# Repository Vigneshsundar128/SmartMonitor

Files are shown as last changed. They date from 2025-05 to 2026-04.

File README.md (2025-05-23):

# Smart Monitor

**Smart Monitor** is an indigenous IoT product designed to monitor energy consumption along with additional features such as weather monitoring, date, and time display. This device leverages open-source libraries and custom firmware with Over-The-Air (OTA) updates to eliminate wired communication, enabling seamless firmware upgrades for continuous feature development and integration within a complete smart ecosystem.

## Features

- Real-time monitoring of energy consumption (voltage, current, power)
- Local temperature and humidity measurement
- Weather updates using OpenWeatherMap API
- Date and time synchronization via NTP server
- OTA firmware updates for hassle-free enhancements
- Web interface hosted on the device for power monitoring
- Non-blocking, efficient firmware using timers, counters, and interrupts

## Hardware Components

- **ESP8266EX** — 32-bit Tensilica® processor-based microcontroller  
- **LCD 20x4** — for local data display (I2C communication)  
- **DHT11** — temperature and humidity sensor  
- **PZEM-004T** — voltage and current sensor (UART communication)  

## Software and Libraries Used

- **Firmware:** Developed using advanced embedded concepts (non-blocking methods, timers, counters, interrupts)  
- **OTA Updates:** [Elegant OTA](https://docs.elegantota.pro/) — open-source library for wireless firmware updates  
- **Weather Data:** OpenWeatherMap API  
- **Time Sync:** NTP server  
- **Web Interface:** Power monitoring webpage adapted from [HowToElectronics](https://howtoelectronics.com)  

## Installation and Setup

1. Install dependencies and libraries (e.g., Elegant OTA, DHT11 library, etc.) through your preferred IDE (e.g., Arduino IDE).

2. Configure WiFi credentials and OpenWeatherMap API key in the firmware source code.

3. Flash the firmware to ESP8266EX using OTA or wired connection for first upload.

4. Access the web interface via the ESP8266 IP address to monitor data.

## Usage

- View energy consumption, temperature, humidity, weather data, date, and time on the LCD display.

- Access the hosted web page on ESP8266 for detailed power monitoring.

- OTA updates allow you to upload new firmware versions without physical connection.

## Project Status

This project is currently active and under continuous development for additional features and optimizations. This have both IoT and IoT firmware. 

## Contribution

Contributions are welcome! Feel free to open issues or submit pull requests with improvements.

## License

This project is licensed under the MIT License. See the LICENSE file for details.

## Author

Vignesh Sundar

LinkedIn: https://www.linkedin.com/in/vignesh-sundar-m/

## References

Elegant OTA Library

OpenWeatherMap API

HowToElectronics for Webpage

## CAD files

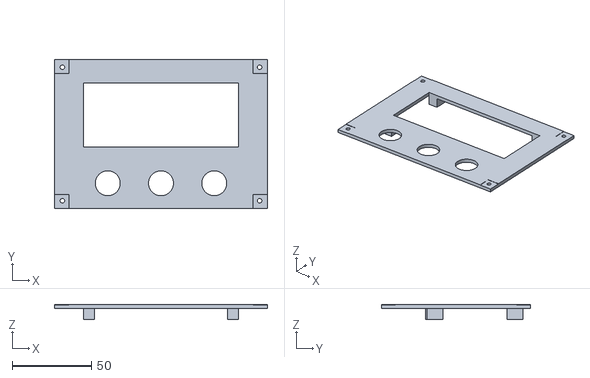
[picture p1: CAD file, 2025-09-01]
3d Case stl/displaypanel.STL
134.0 x 94.0 x 9.40

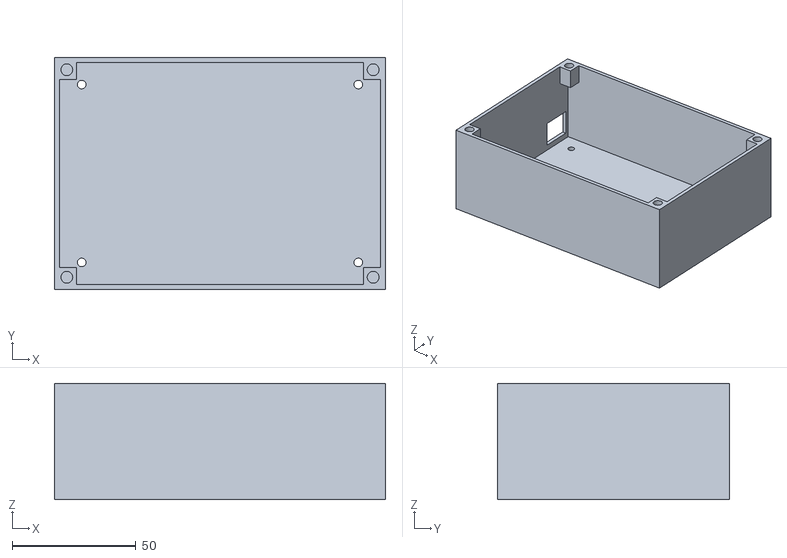
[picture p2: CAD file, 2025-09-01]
3d Case stl/energymeter_case.STL
134.0 x 94.0 x 47.0

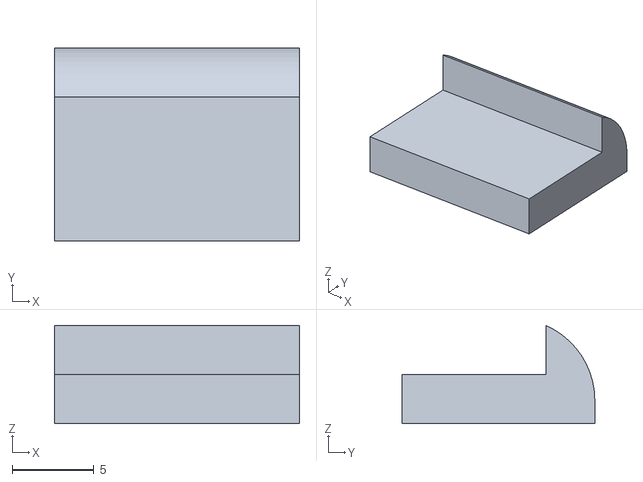
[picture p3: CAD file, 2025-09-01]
3d Case stl/latch.STL
15.0 x 11.8 x 6.00

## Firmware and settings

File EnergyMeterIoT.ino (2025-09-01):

#include <ESP8266WiFi.h>
#include <ESP8266HTTPClient.h> 
#include <ESPAsyncTCP.h>
#include <ESPAsyncWebServer.h>
#include <WiFiClientSecure.h> 
#include <WiFiClient.h>
#include <WiFiUdp.h>
#include <LiquidCrystal_I2C.h>
#include <NTPClient.h>
#include <TimeLib.h> 
#include <ArduinoJson.h>
#include <PZEM004Tv30.h>
#include <SoftwareSerial.h>
#include <ElegantOTA.h> // Set for #define ELEGANTOTA_USE_ASYNC_WEBSERVER 1
#include "DHT.h"

#define DHTTYPE DHT11   // DHT 11

// Global Variable
int sec = 0, myMinute = 0;
int prevDisplay = -1;
float temp;
int humidity;
const char* weatherDesc = "Updating...";
volatile bool screenToggle = false;
volatile bool LCD_LED = false;
volatile unsigned long lastInterruptTime = 0;
int currentScreen = 0;
const unsigned long debounceDelay = 500;  // 500 ms debounce
unsigned long lastLcdClear = 0;
const unsigned long clearInterval = 60000; // 60 seconds
uint8_t DHTPin = D3; 
float Temperature;
float Humidity;
float voltage = 0.0;
float current = 0.0;
float power = 0.0;
float energy = 0.0;
float frequency = 0.0;
float pf = 0.0;

// set the LCD address to 0x3F for a 16 chars and 2 line display
LiquidCrystal_I2C lcd(0x27,20,4);  

// set user and password
const char *ssid     = "";//Enter SSID
const char *password = "";//Enter your password

AsyncWebServer server(80);  // server port

const char* serverUrl = ""; //Set API

const long utcOffsetInSeconds = 19800;// set time +5:30 INDIA

// Define NTP Client to get time
WiFiUDP ntpUDP;
NTPClient timeClient(ntpUDP, "pool.ntp.org", utcOffsetInSeconds);

//set input for pzem sensor to UART
SoftwareSerial pzemSerial(D6, D7); // RX, TX
PZEM004Tv30 pzem(pzemSerial);
               
// Initialize DHT sensor.
DHT dht(DHTPin, DHTTYPE);                

byte rightArrow[8] = {
  0b00000,
  0b00100,
  0b00010,
  0b11111,
  0b00010,
  0b00100,
  0b00000,
  0b00000
};

byte clockSymbol[8] = {
  0b00000,
  0b01110,
  0b10101,
  0b10111,
  0b10001,
  0b01110,
  0b00000,
  0b00000
};

byte smilesymbol[8] = {
  0b00000,
  0b01010,
  0b01010,
  0b00000,
  0b00000,
  0b10001,
  0b01110,
  0b00000
};

byte lightningSymbol[8] = {
  0b00100,
  0b01100,
  0b11110,
  0b00110,
  0b01100,
  0b11100,
  0b01000,
  0b00000
};

const char index_html[] PROGMEM = R"rawliteral(
<!DOCTYPE HTML>
<html>
<head>
  <title>Power Monitor</title>
  <meta name="viewport" content="width=device-width, initial-scale=1">
  <link rel="stylesheet" href="https://cdnjs.cloudflare.com/ajax/libs/font-awesome/6.0.0/css/all.min.css">
  <style>
    body { 
      font-family: Arial, sans-serif; 
      margin: 0;
      padding: 20px;
      background-color: #f0f0f0;
    }
    .grid {
      display: grid;
      grid-template-columns: repeat(auto-fit, minmax(300px, 1fr));
      gap: 20px;
      max-width: 1200px;
      margin: 0 auto;
    }
    .card {
      background: white;
      border-radius: 15px;
      padding: 25px;
      box-shadow: 0 4px 8px rgba(0,0,0,0.1);
      display: flex;
      align-items: center;
      text-align: left;
    }
    .icon {
      font-size: 40px;
      margin-right: 25px;
      min-width: 50px;
      text-align: center;
    }
    .content {
      display: flex;
      flex-direction: column;
    }
    .label {
      font-size: 16px;
      color: #7f8c8d;
      margin-bottom: 5px;
      font-weight: bold;
    }
    .value {
      font-size: 24px;
      color: #2c3e50;
      display: flex;
      align-items: baseline;
    }
    .unit {
      font-size: 16px;
      color: #95a5a6;
      margin-left: 5px;
    }
    .fa-bolt { color: #f1c40f; }
    .fa-exchange-alt { color: #3498db; }
    .fa-plug { color: #e74c3c; }
    .fa-chart-line { color: #2ecc71; }
    .fa-wave-square { color: #9b59b6; }
    .fa-percent { color: #e67e22; }
    h1 {
      text-align: center;
      margin: 30px 0;
      color: #2c3e50;
    }
  </style>
  <script>
    function updateData() {
      var xhttp = new XMLHttpRequest();
      xhttp.onreadystatechange = function() {
        if (this.readyState == 4 && this.status == 200) {
          var data = JSON.parse(this.responseText);
          document.getElementById('voltage').innerHTML = data.voltage + '<span class="unit">V</span>';
          document.getElementById('current').innerHTML = data.current + '<span class="unit">A</span>';
          document.getElementById('power').innerHTML = data.power + '<span class="unit">W</span>';
          document.getElementById('energy').innerHTML = data.energy + '<span class="unit">kWh</span>';
          document.getElementById('frequency').innerHTML = data.frequency + '<span class="unit">Hz</span>';
          document.getElementById('pf').innerHTML = data.pf;
        }
      };
      xhttp.open("GET", "/data", true);
      xhttp.send();
    }
    setInterval(updateData, 2000);
    window.onload = updateData;
  </script>
</head>
<body>
  <h1><i class="fas fa-plug"></i> ESP32 Power Monitor</h1>
  <div class="grid">
    <div class="card">
      <i class="fas fa-bolt icon"></i>
      <div class="content">
        <div class="label">VOLTAGE</div>
        <div class="value" id="voltage">%VOLTAGE%<span class="unit">V</span></div>
      </div>
    </div>
    <div class="card">
      <i class="fas fa-exchange-alt icon"></i>
      <div class="content">
        <div class="label">CURRENT</div>
        <div class="value" id="current">%CURRENT%<span class="unit">A</span></div>
      </div>
    </div>
    <div class="card">
      <i class="fas fa-plug icon"></i>
      <div class="content">
        <div class="label">POWER</div>
        <div class="value" id="power">%POWER%<span class="unit">W</span></div>
      </div>
    </div>
    <div class="card">
      <i class="fas fa-chart-line icon"></i>
      <div class="content">
        <div class="label">ENERGY</div>
        <div class="value" id="energy">%ENERGY%<span class="unit">kWh</span></div>
      </div>
    </div>
    <div class="card">
      <i class="fas fa-wave-square icon"></i>
      <div class="content">
        <div class="label">FREQUENCY</div>
        <div class="value" id="frequency">%FREQUENCY%<span class="unit">Hz</span></div>
      </div>
    </div>
    <div class="card">
      <i class="fas fa-percent icon"></i>
      <div class="content">
        <div class="label">POWER FACTOR</div>
        <div class="value" id="pf">%PF%</div>
      </div>
    </div>
  </div>
</body>
</html>
)rawliteral";
 
String processor(const String& var) {
  if(var == "VOLTAGE") return isnan(voltage) ? "Error" : String(voltage, 1);
  else if(var == "CURRENT") return isnan(current) ? "Error" : String(current, 2);
  else if(var == "POWER") return isnan(power) ? "Error" : String(power, 1);
  else if(var == "ENERGY") return isnan(energy) ? "Error" : String(energy, 3);
  else if(var == "FREQUENCY") return isnan(frequency) ? "Error" : String(frequency, 1);
  else if(var == "PF") return isnan(pf) ? "Error" : String(pf, 2);
  return String();
}

//Interrupt for Screen toggle
void IRAM_ATTR handleInterrupt1() {
  unsigned long currentTime = millis();
  if (currentTime - lastInterruptTime > debounceDelay) {
    screenToggle = true;
    lastInterruptTime = currentTime;
  }
}

//Interrupt for LED 
void IRAM_ATTR handleInterrupt2() { 
  unsigned long currentTime = millis();
  if (currentTime - lastInterruptTime > debounceDelay) {
    LCD_LED = !LCD_LED;
    lastInterruptTime = currentTime;
  }
}

void setup() {
  lcd.init();
  lcd.clear();         
  lcd.backlight();      // Make sure backlight is on

  Serial.begin(115200);
  pzemSerial.begin(9600);

  lcd.createChar(1, rightArrow);
  lcd.createChar(2, clockSymbol);
  lcd.createChar(3, smilesymbol);
  lcd.createChar(4, lightningSymbol);

  WiFi.begin(ssid, password);

  while ( WiFi.status() != WL_CONNECTED ) {
    delay ( 500 );
    Serial.print ( "." );
    lcd.setCursor(5,0);
    lcd.print(" Hello ");
    lcd.write(byte(3));
    lcd.setCursor(4,1);
    lcd.print(" ");  // ADD DEVICE NAME
    lcd.setCursor(4,2);
    lcd.print("Booting up");
    lcd.setCursor(0,3);
    lcd.print("connecting Wifi ...");
  }

  lcd.clear();

  setupOTA();

  pinMode(14, INPUT_PULLUP);  // Button to change screen
  pinMode(2, INPUT_PULLUP);  // Button to turn on or off LCD Led
  attachInterrupt(digitalPinToInterrupt(14), handleInterrupt1, FALLING);
  attachInterrupt(digitalPinToInterrupt(2), handleInterrupt2, FALLING);

  showScreen(currentScreen);  // Show initial screen

  timeClient.begin();

  pinMode(DHTPin, INPUT);
  dht.begin();  
}

void loop() {
  ElegantOTA.loop();

  sec = timer();

  // Enable this for automatic screen change for every 10sec
  // int secBlock = sec / 10;
  // int display = 0;

  // if (secBlock == 0 || secBlock == 3)
  //   display = 1;
  // else if (secBlock == 1 || secBlock == 4)
  //   display = 2;
  // else if (secBlock == 2 || secBlock == 5)
  //   display = 3;

  // // Only clear and update when screen changes
  // if (display != prevDisplay) {
  //   lcd.clear();
  //   prevDisplay = display;
  // }

  // switch (display) {
  //   case 1: Sensor_temp(); break;
  //   case 2: Time(); break;
  //   case 3: energy(); break;
  // }

  // button input for change screen
  if (screenToggle) {
      screenToggle = false;
      currentScreen = (currentScreen + 1) % 4;
      lcd.clear(); 
    }

    // Update screen content continuously
    showScreen(currentScreen);
  }

  void showScreen(int screen) {
    switch (screen) {
    case 0:
      Time();
      break;
    case 1:
      EnergyScreen();
      break;
    case 2:
      Sensor_temp();
      break; 
    case 3:
      deviceinfo(); 
      break;  
  }

  if (LCD_LED) {
    lcd.backlight();
  }else{
    lcd.noBacklight();
  }

  // Call weather function every 10 minutes
  if (sec >= 59) {
    myMinute++;
    if (myMinute == 10) {
      myMinute = 0;
      weather();
    }
  }

  Energy();

}

void deviceinfo(){
  lcd.setCursor(4,0);
  lcd.print("Device INFO");
  lcd.setCursor(0,1);
  lcd.print("IP:");
  lcd.setCursor(3,1);
  lcd.print(WiFi.localIP());
  lcd.setCursor(0,2);
  lcd.print("ID:");
  lcd.setCursor(3,2);
  lcd.print(WiFi.macAddress());
  lcd.setCursor(0,3);
  lcd.print("Firmware ver 2.0");
}

//OTA updater don't remove for feature update's
void setupOTA() {
  Serial.println();
  Serial.println("WiFi connected");
  Serial.print("IP address: ");
  Serial.println(WiFi.localIP());
  Serial.print("MAC address: ");
  Serial.println(WiFi.macAddress());
  // Route for root / web page
  server.on("/", HTTP_GET, [](AsyncWebServerRequest *request){
    request->send_P(200, "text/html", index_html, processor);
  });
  // Route for JSON data
  server.on("/data", HTTP_GET, [](AsyncWebServerRequest *request){
    String json = "{";
    json += "\"voltage\":\"" + String(isnan(voltage) ? "Error" : String(voltage, 1)) + "\",";
    json += "\"current\":\"" + String(isnan(current) ? "Error" : String(current, 2)) + "\",";
    json += "\"power\":\"" + String(isnan(power) ? "Error" : String(power, 1)) + "\",";
    json += "\"energy\":\"" + String(isnan(energy) ? "Error" : String(energy, 3)) + "\",";
    json += "\"frequency\":\"" + String(isnan(frequency) ? "Error" : String(frequency, 1)) + "\",";
    json += "\"pf\":\"" + String(isnan(pf) ? "Error" : String(pf, 2)) + "\"";
    json += "}";
    request->send(200, "application/json", json);
  });
  ElegantOTA.begin(&server);
  server.begin();
  Serial.println("HTTP server started");
}

int timer(){
  timeClient.update();
  time_t epochTime = timeClient.getEpochTime();
  sec = second(epochTime);
  return sec;
}

void Time(){
  timeClient.update();

  time_t epochTime = timeClient.getEpochTime();

  const char* daysOfWeek[7] = {
    "Sunday", "Monday", "Tuesday", "Wednesday",
    "Thursday", "Friday", "Saturday"
  };

  int yr = year(epochTime);
  int mn = month(epochTime);
  int dy = day(epochTime);

  int hr = hour(epochTime);
  int mi = minute(epochTime);
  int se = second(epochTime);

  int wkday = weekday(epochTime); // 1 = Sunday, 7 = Saturday
  const char* dayName = daysOfWeek[wkday - 1];

  Serial.printf("Date: %s %d-%02d-%02d\n", dayName, yr, mi, dy);
  Serial.printf("Time: %02d:%02d:%02d\n", hr, mn, se);

  lcd.setCursor(3,0);
  lcd.print("Data and Time");
  lcd.write(byte(2));
  
  // for date in LCD
  lcd.setCursor(2,1);
  lcd.printf("Date: %02d/%02d/%04d", dy, mn, yr);
  
  //for time in LCD
  lcd.setCursor(2,2);
  lcd.printf("Time: %02d:%02d:%02d %s", 
  (hr % 12 == 0) ? 12 : (hr % 12), mi, se, (hr < 12) ? "AM" : "PM");

  // Day Name
  if (millis() - lastLcdClear >= clearInterval) {
    lcd.setCursor(0, 3);
    lcd.print("                    ");  // 20 spaces for 20x4 LCD
    lastLcdClear = millis();
  }
  lcd.setCursor(3,3);
  lcd.printf("Day: %s", dayName);

  delay(1000);
}


void Sensor_temp(){
  Temperature = dht.readTemperature(); // Gets the values of the temperature
  Humidity = dht.readHumidity(); // Gets the values of the humidity 

  // Title
  lcd.setCursor(0,0);
  lcd.print("Weather");
  lcd.setCursor(15,0);
  lcd.print("Ch,IN");

  //Local weather from DHT11
  lcd.setCursor(0,1);
  lcd.print("L"); // local data
  lcd.write(byte(1));
  lcd.printf("Temp:%d%cC Hum:%d%%", (int)Temperature, 223, (int)Humidity);

  // Internet weather
  lcd.setCursor(0,2);
  lcd.print("S"); // Internet data
  lcd.write(byte(1));
  lcd.print("Temp:");
  lcd.print((int)temp);
  lcd.write(223);  // Degree symbol
  lcd.print("C Hum:");
  lcd.print((int)humidity);
  lcd.print("%");

  //weather description
  if (millis() - lastLcdClear >= clearInterval) {
    lcd.setCursor(0, 3);
    lcd.print("                    ");  // 20 spaces for 20x4 LCD
    lastLcdClear = millis();
  }
  lcd.setCursor(0,3);
  lcd.write(byte(1));
  lcd.print(weatherDesc);

}

void weather(){
  WiFiClientSecure client;
  client.setInsecure();  //Skip certificate verification

  HTTPClient http;
  http.begin(client, serverUrl);  //Use HTTPS and secure client

  int httpCode = http.GET();

  if (httpCode > 0) {
    String payload = http.getString();
    Serial.println("Received JSON:");
    Serial.println(payload);

  StaticJsonDocument<2048> doc;
  DeserializationError error = deserializeJson(doc, payload);

  if (!error) {
    // Access first item in forecast list
    JsonObject forecast = doc["list"][0];

    temp = forecast["main"]["temp"];
    humidity = forecast["main"]["humidity"];
    const char* weatherMain = forecast["weather"][0]["main"];
    weatherDesc = forecast["weather"][0]["description"];
    const char* time = forecast["dt_txt"];

    Serial.print("Forecast Time: ");
    Serial.println(time);
    
    Serial.print("Temperature: ");
    Serial.println(temp);

    Serial.print("Humidity: ");
    Serial.println(humidity);

    Serial.print("Weather: ");
    Serial.println(weatherMain);

    Serial.print("Description: ");
    Serial.println(weatherDesc);
  } else {
    Serial.print("JSON parse error: ");
    Serial.println(error.c_str());
  }

  } else {
    Serial.print("HTTP GET failed: ");
    Serial.println(http.errorToString(httpCode).c_str());
  }

  http.end();
}

void Energy(){
  unsigned long previousMillis =0;
  unsigned long interval = 2000; // for 1 sec
  unsigned long currentMillis = millis();

  if(currentMillis - previousMillis >= interval){
    previousMillis = currentMillis;
    // Read data from the PZEM sensor
    voltage   = pzem.voltage();
    current   = pzem.current();
    power     = pzem.power();
    energy    = pzem.energy();
    frequency = pzem.frequency();
    pf        = pzem.pf();
  }
}

void EnergyScreen(){

    if(isnan(voltage)){
        Serial.println("Error reading voltage");
    } else if (isnan(current)) {
        Serial.println("Error reading current");
    } else if (isnan(power)) {
        Serial.println("Error reading power");
    } else if (isnan(energy)) {
        Serial.println("Error reading energy");
    } else if (isnan(frequency)) {
        Serial.println("Error reading frequency");
    } else if (isnan(pf)) {
        Serial.println("Error reading power factor");
    } else {
        //Print values
        Serial.printf("Voltage: %g V", voltage); 
        Serial.printf("Current: %g A", current); 
        Serial.printf("Power: %g W", power); 
        Serial.printf("Energy: %g Kwh", energy); 
        Serial.printf("Frequency: %g Hz", frequency); 
        Serial.printf("Power Factor: %g", pf);
    }

    lcd.setCursor(4,0);
    lcd.print("Energy Meter");
    lcd.write(byte(4));
    lcd.setCursor(0,1);
    lcd.printf("V:%.1fV", voltage); 
    lcd.setCursor(16, 1);
    lcd.print("   ");// Avoid ghost character of A
    lcd.setCursor(10,1);
    lcd.printf("C:%.2fA", current);
    lcd.setCursor(5, 2);
    lcd.print("    "); // Avoid ghost character of W
    lcd.setCursor(0,2);
    lcd.printf("P:%.1fW", power);
    lcd.setCursor(10,2); 
    lcd.printf("E:%.1fkW", energy);
    lcd.setCursor(0,3); 
    lcd.printf("F:%.1fHz", frequency); 
    lcd.setCursor(10,3); 
    lcd.printf("PF:%.2f", pf);

    delay(1000);
 
    Serial.println();
}

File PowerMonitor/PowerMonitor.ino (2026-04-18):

#include <Arduino.h>
#include "wifi_manager.h"
#include "ota_manager.h"
#include "lcd_display.h"
#include "dht_sensor.h"
#include "pzem_driver.h"
#include "weather.h"
#include "webserver.h"
#include "timekeeper.h"
#include "config.h"

// Application-wide globals 
extern volatile bool screenToggle;
extern volatile bool LCD_LED;

void IRAM_ATTR onScreenButton(); // forward (implemented in lcd_display)
void IRAM_ATTR onBacklightButton();

void setup() {
  Serial.begin(115200);
  delay(100);

  // Initialize subsystems
  lcd_init();
  lcd_clear();

  wifi_begin();
  ota_setup();  // sets up ElegantOTA 
  timekeeper_begin();
  dht_begin();
  pzem_begin();
  weather_begin();

  // Attach interrupts (pins defined in lcd_display)
  pinMode(BTN_SCREEN_PIN, INPUT_PULLUP);
  pinMode(BTN_LED_PIN, INPUT_PULLUP);
  attachInterrupt(digitalPinToInterrupt(BTN_SCREEN_PIN), onScreenButton, FALLING);
  attachInterrupt(digitalPinToInterrupt(BTN_LED_PIN), onBacklightButton, FALLING);

  show_screen(0);
  webserver_begin(); // starts webserver routes
}

void loop() {
  ota_loop();
  lcd_process();
  wifi_update();
  timekeeper_update();

  static int currentScreen = 0;
  if (screenToggle) {
    screenToggle = false;
    currentScreen = (currentScreen + 1) % 4;
    lcd_clear();
  }

  static unsigned long lastDisplayUpdate = 0;
  if (millis() - lastDisplayUpdate >= 500) {
    lastDisplayUpdate = millis();

    switch (currentScreen) {
      case 0: timekeeper_display(); break;
      case 1: energy_display(); break;
      case 2: sensor_display(); break;
      case 3: device_info_display(); break;
    }
  }

  // periodic tasks
  static unsigned long lastWeather = 0;
  static bool initialWeatherFetched = false;
  if (!initialWeatherFetched && wifi_is_connected()) {
    weather_update();
    lastWeather = millis();
    initialWeatherFetched = true;
  }

  if (millis() - lastWeather >= Config::Weather::kRefreshIntervalMs) {
    lastWeather = millis();
    weather_update();
  }

  static unsigned long lastPzemUpdate = 0;
  if (millis() - lastPzemUpdate >= 1000) {
    lastPzemUpdate = millis();
    pzem_update();
  }

  delay(20);
}

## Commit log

2025-09-01 updates firmware version remove bug and add device info screen and add 3d case stl file for printing case for device
    [displaypanel.STL, energymeter_case.STL, latch.STL]
2026-04-18 Fixes of major issue
    The flicker was happening because the LCD was being hammered too often while the web UI was active. In your firmware, each screen was being redrawn repeatedly in the main loop, some display functions had blocking delay(1000), and the backlight interrupt was calling LCD functions directly. When you open the webpage, Wi‑Fi and /data requests add more timing pressure, so those LCD/I2C updates become visibly unstable.
    I fixed that in the display path. The main changes are in PowerMonitor.ino (line 42) and lcd_display.cpp (line 41): LCD work is now processed safely in loop(), not inside the ISR; the screen refresh is throttled; pzem_update() is throttled separately; and th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
    [PowerMonitor.ino, weather.cpp]
2026-04-18 Added config file
    I added a single shared config file. You can now change the common settings in one place instead of editing multiple files.
    Right now this centralizes:
    Wi‑Fi SSID and password
    Firmware version
    Device name
    NTP server and timezone offset
    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
